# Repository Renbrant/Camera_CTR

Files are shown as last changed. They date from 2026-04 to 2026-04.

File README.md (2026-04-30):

# Camera CTR - High-Speed & Lightning Photography Trigger

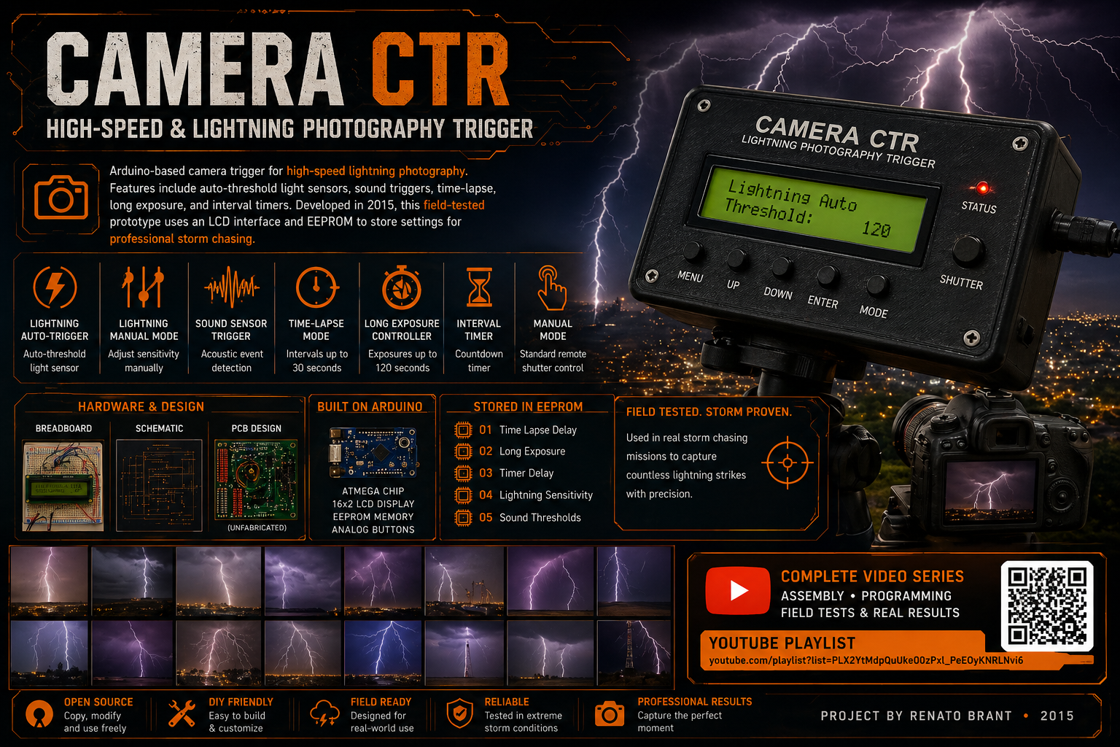
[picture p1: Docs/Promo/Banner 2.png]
Camera CTR Banner


### Description
**Arduino-based camera trigger for high-speed lightning photography. Features include auto-threshold light sensors, sound triggers, time-lapse, long exposure, and interval timers. Developed in 2015, this field-tested prototype uses an LCD interface and EEPROM to store settings for professional storm chasing.**

## Prototype & Hardware Design
The device evolved through several iterations, from early breadboard tests to a finalized prototype with a dedicated housing. 

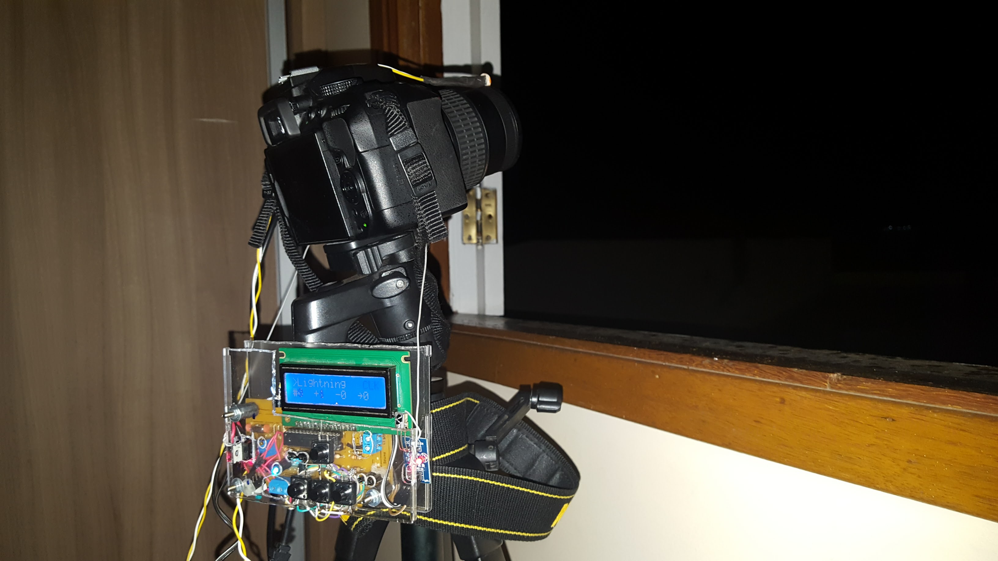
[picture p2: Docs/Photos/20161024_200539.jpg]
Camera CTR Prototype


### Hardware Schematics & PCB
Although the custom PCB was not manufactured at the time, the project includes complete design files for the circuit and board layout.

| Breadboard View | Schematic | PCB Design (Unfabricated) |
| :---: | :---: | :---: |
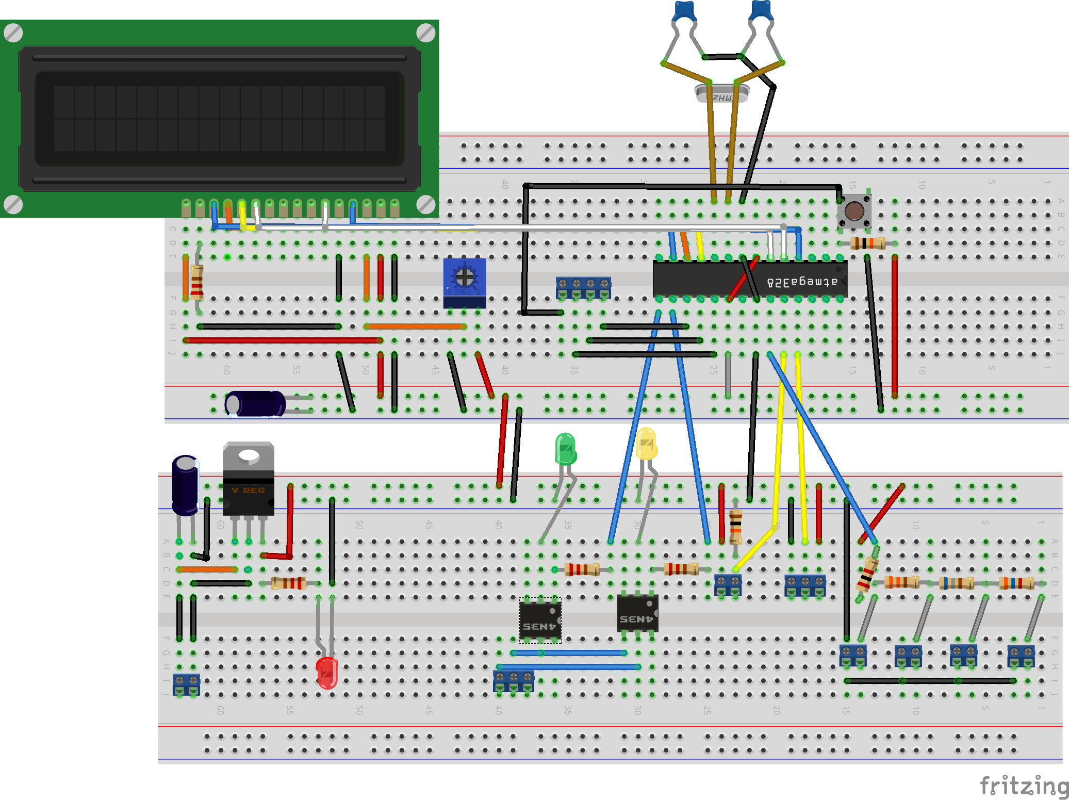
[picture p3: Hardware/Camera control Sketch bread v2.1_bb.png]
Breadboard
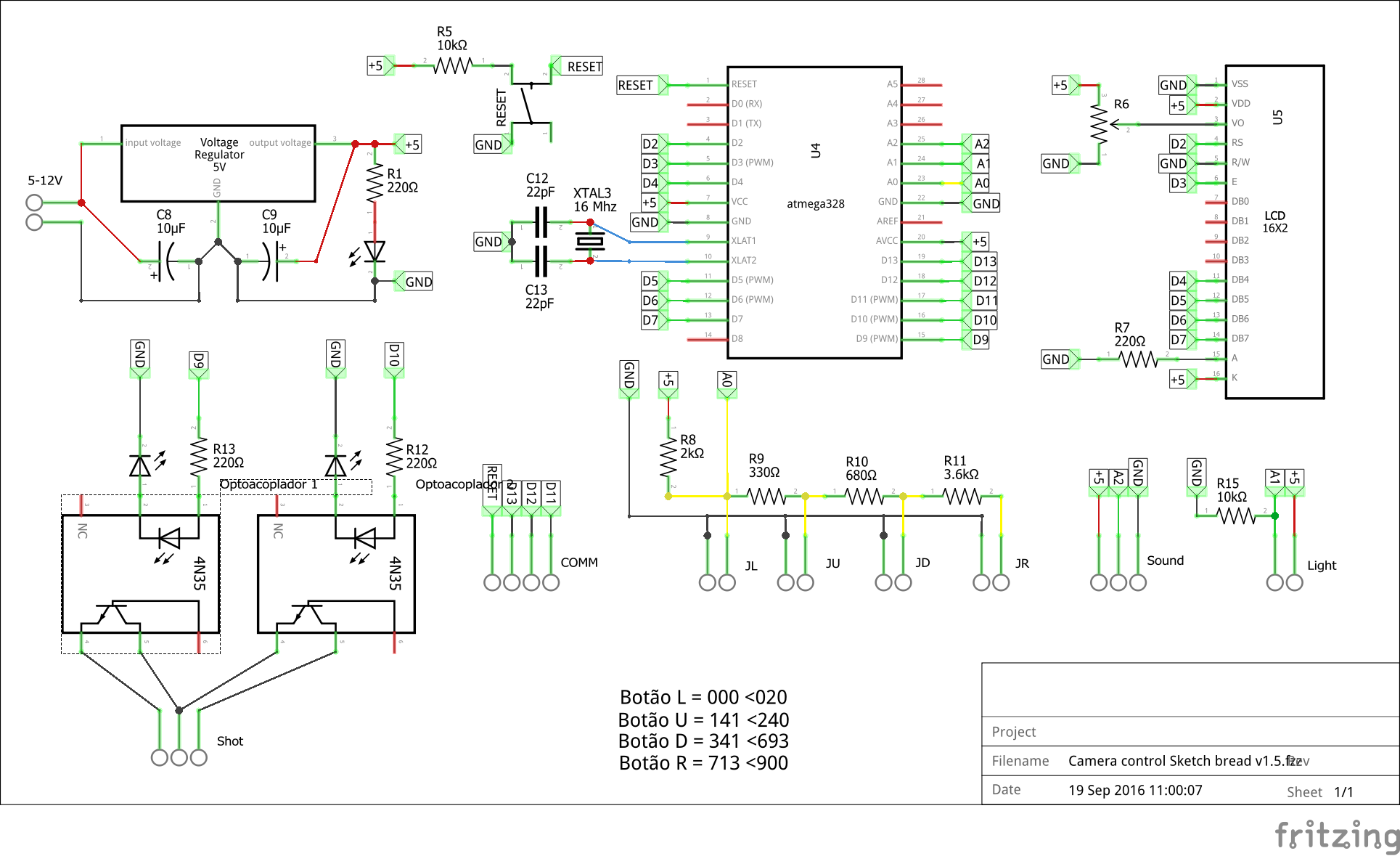
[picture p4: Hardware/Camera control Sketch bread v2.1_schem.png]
Schematic
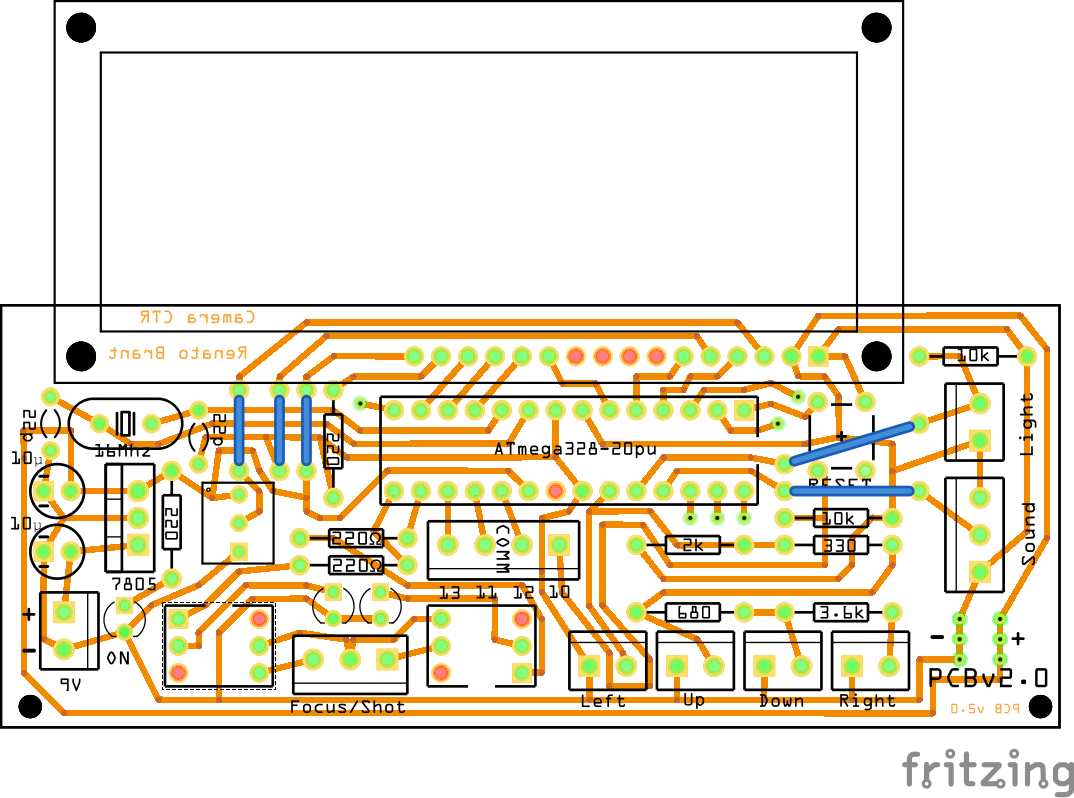
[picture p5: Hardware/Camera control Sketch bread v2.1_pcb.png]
PCB Layout
|  |  |  |

## Features
* **Lightning Auto-Trigger**: Automatically calculates sensitivity thresholds based on ambient light to capture strikes instantly.
* **Lightning Manual Mode**: Manual adjustment of light sensitivity for specific conditions.
* **Sound Sensor Trigger**: Fires the camera based on acoustic events with adjustable sensitivity.
* **Time-Lapse Mode**: Captures sequences with programmable intervals up to 30 seconds.
* **Long Exposure Controller**: Precision shutter control for exposures up to 120 seconds.
* **Interval Timer**: Countdown timer for delayed photography.
* **Manual Mode**: Standard digital remote shutter functionality.
* **Backlight Management**: Dedicated control to toggle LCD light during night shoots.

## Hardware Configuration
The project is built on the Arduino platform using an ATmega chip and a 16x2 LCD. 
The pin mapping as defined in the source code is:

| Component | Pin |
| :--- | :--- |
| **Camera Shutter (Trigger)** | 10 |
| **Ready/Status LED** | 9 |
| **Photometer (Light Sensor)** | A1 |
| **Sound Sensor** | A2 |
| **LCD Backlight Control** | A5 |
| **Keypad (Analog Buttons)** | A0 |

### LCD Pinout (LiquidCrystal)
* **RS**: 2, **Enable**: 3, **D4-D7**: 4, 5, 6, 7.

## Software Logic & Memory
The system utilizes the internal EEPROM to persist user settings across power cycles:
* **EEPROM 01**: Time Lapse Delay settings.
* **EEPROM 02**: Long Exposure parameters.
* **EEPROM 03**: Timer Delay.
* **EEPROM 04**: Lightning Manual Sensitivity.
* **EEPROM 05**: Sound Sensor Thresholds.

## Photo Gallery (Captured with Camera CTR)
Below are photos captured during storms, demonstrating the precision of the synchronized trigger with lightning discharges.

| | | |
|:---:|:---:|:---:|
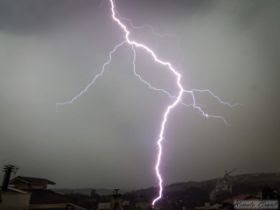
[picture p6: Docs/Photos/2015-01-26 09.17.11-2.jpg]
Lightning 1
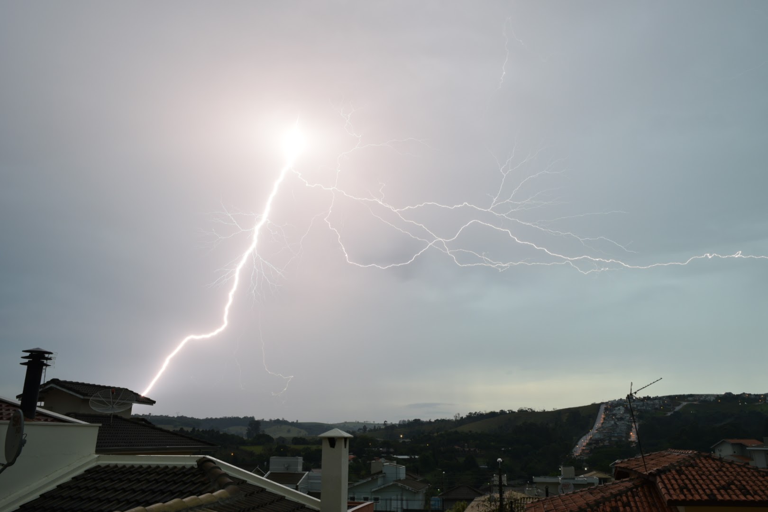
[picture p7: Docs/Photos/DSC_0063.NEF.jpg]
Lightning 2
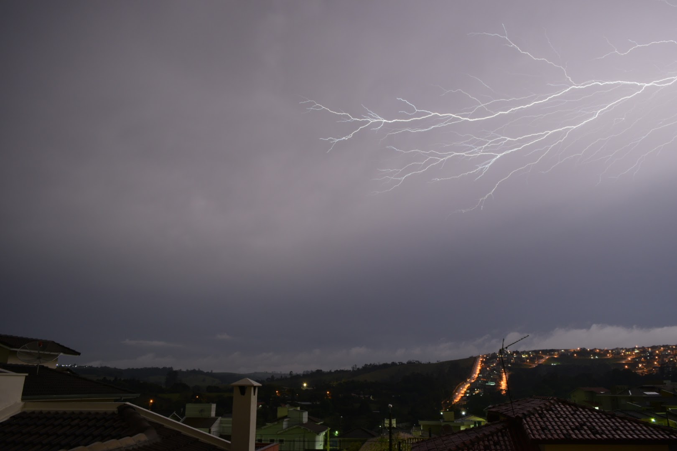
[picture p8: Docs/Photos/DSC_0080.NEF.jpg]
Lightning 3
|  |  |  |
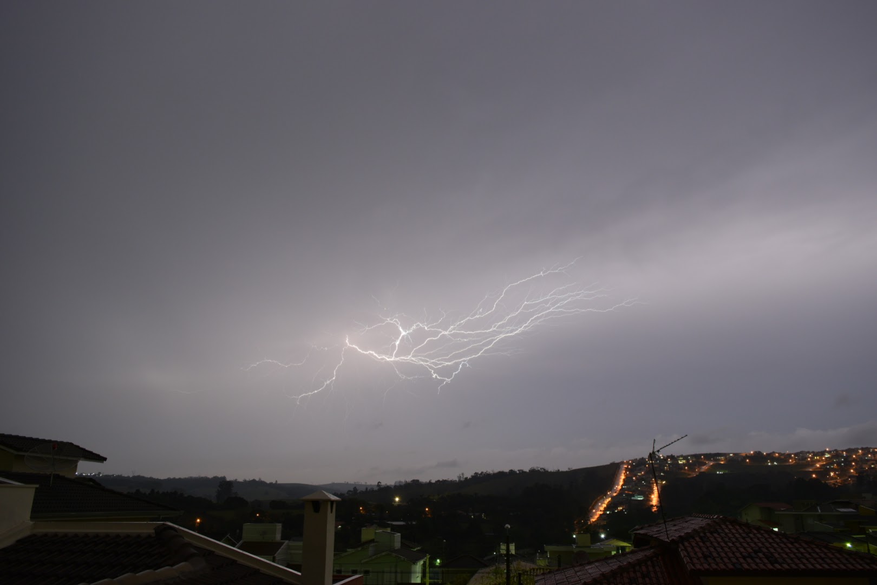
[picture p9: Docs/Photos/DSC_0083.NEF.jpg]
Lightning 4
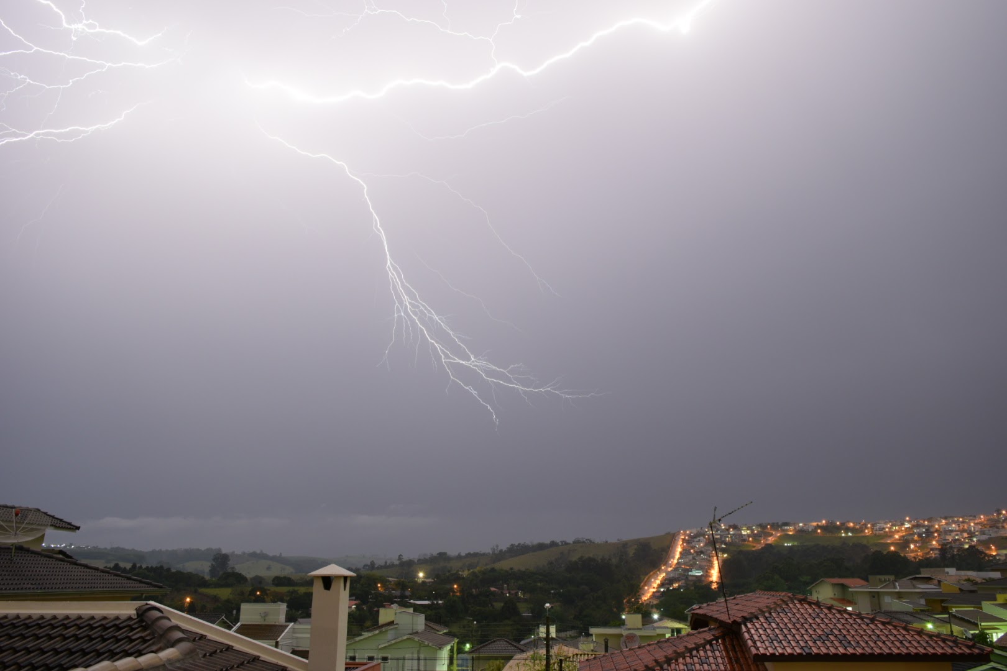
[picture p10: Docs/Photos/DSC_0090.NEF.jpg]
Lightning 5
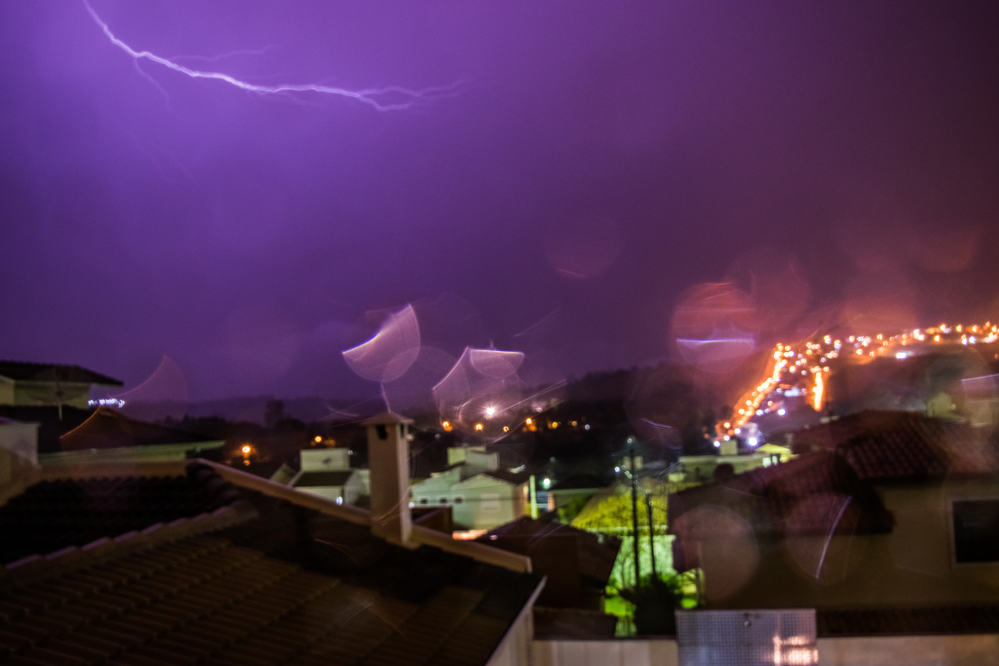
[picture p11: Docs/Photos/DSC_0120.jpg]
Lightning 6
|  |  |  |
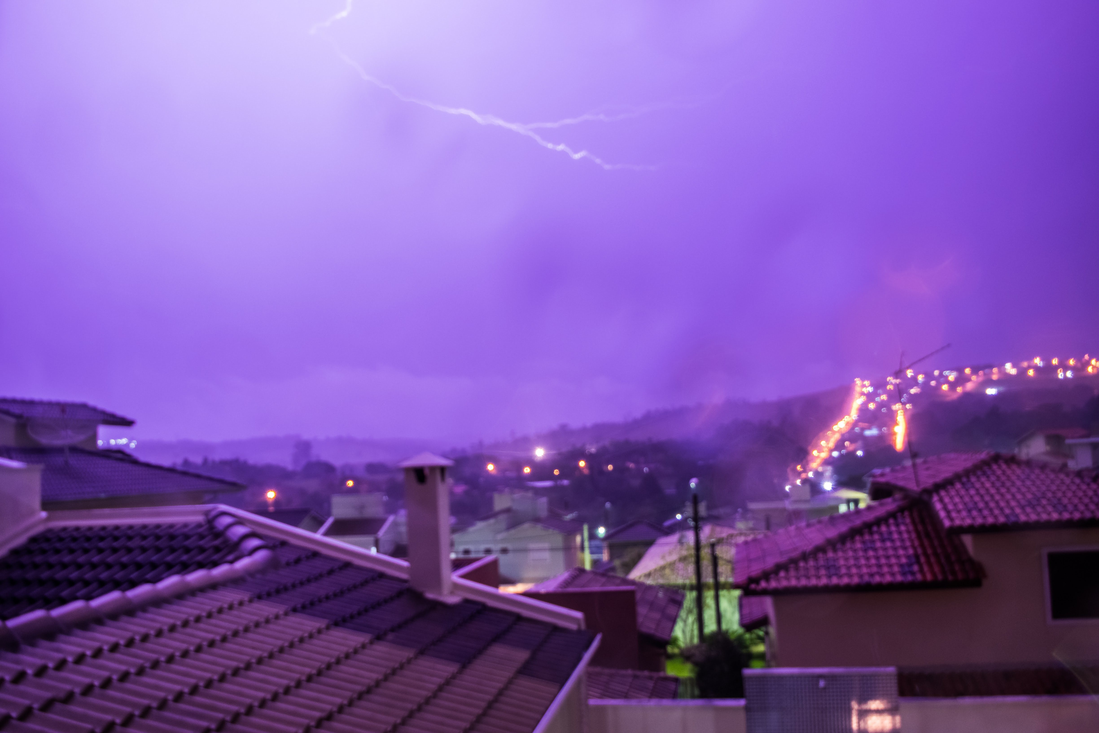
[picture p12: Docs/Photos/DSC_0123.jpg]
Lightning 7
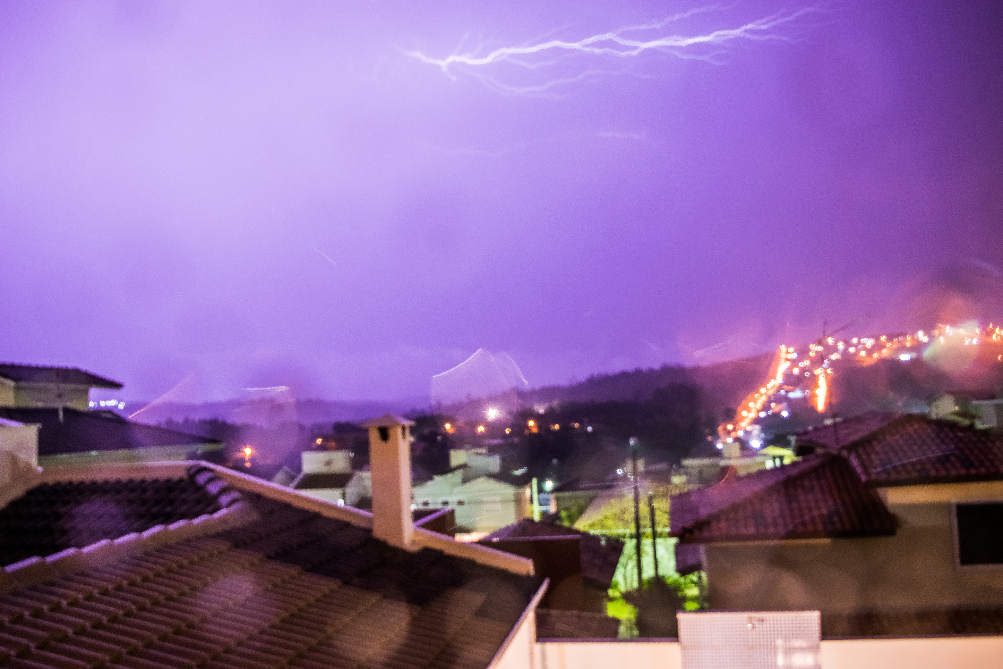
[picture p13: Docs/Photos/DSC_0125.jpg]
Lightning 8
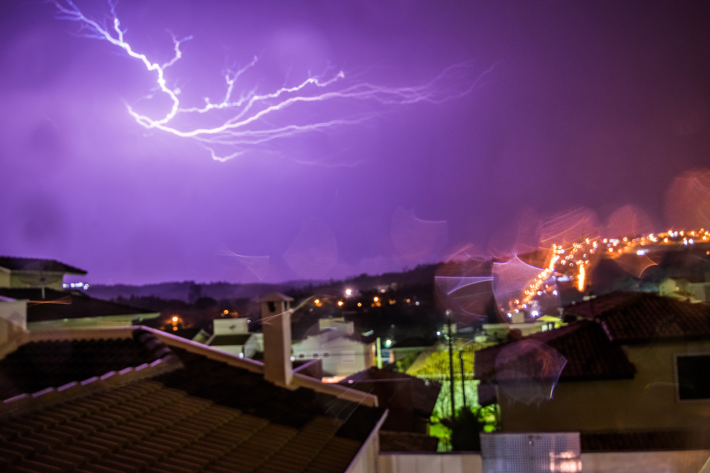
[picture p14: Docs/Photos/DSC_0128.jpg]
Lightning 9
|  |  |  |
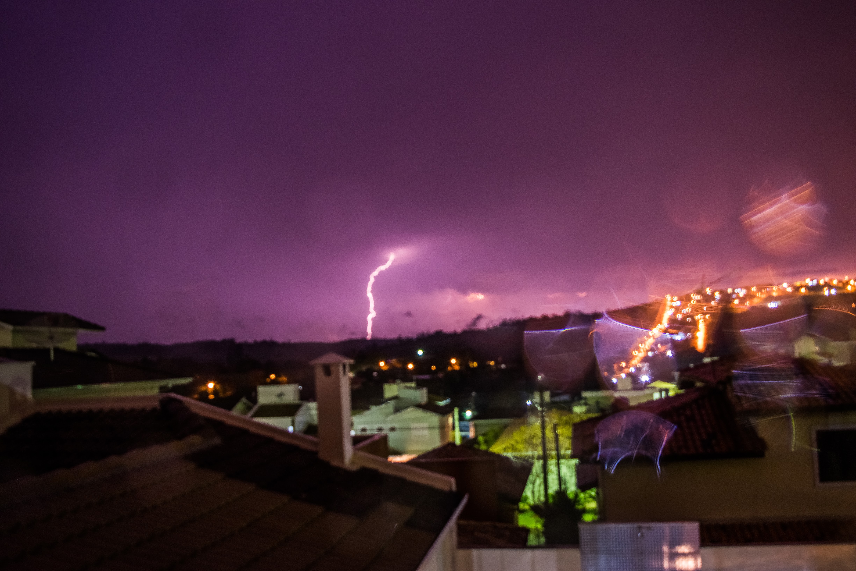
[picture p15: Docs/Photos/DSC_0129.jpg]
Lightning 10
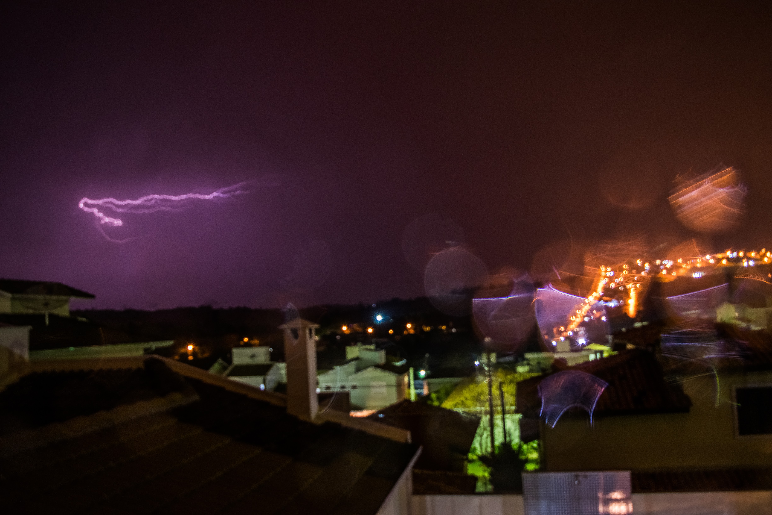
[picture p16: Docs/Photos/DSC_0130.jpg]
Lightning 11
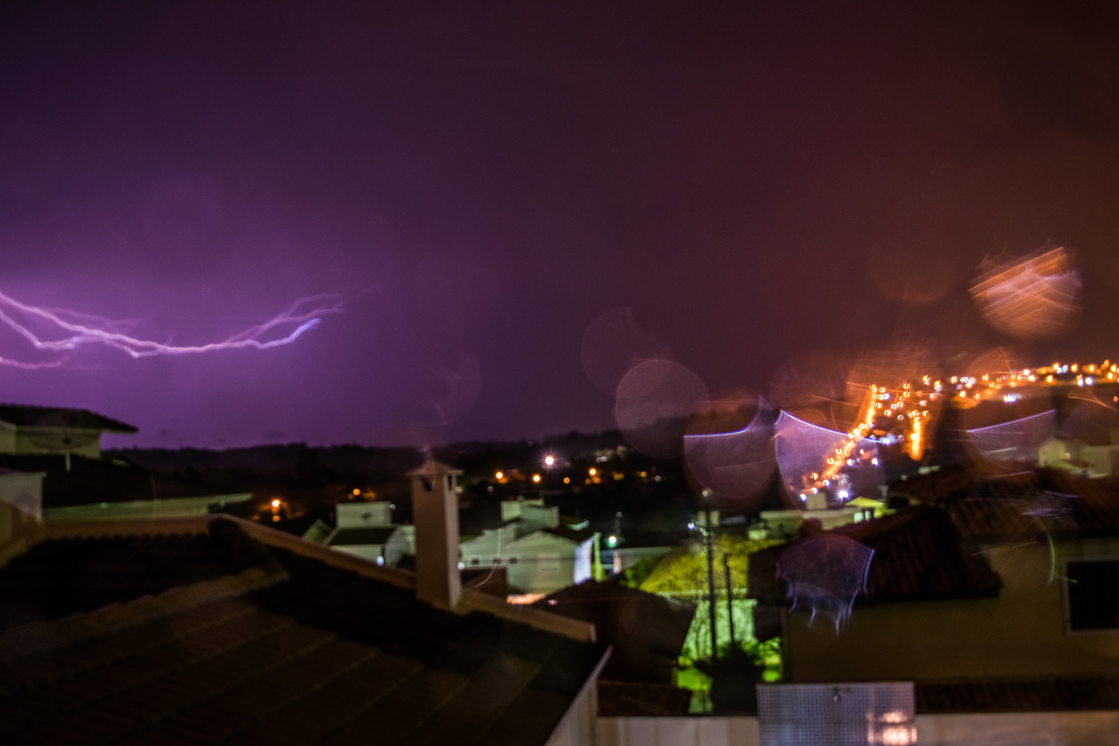
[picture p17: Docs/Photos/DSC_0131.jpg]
Lightning 12
|  |  |  |
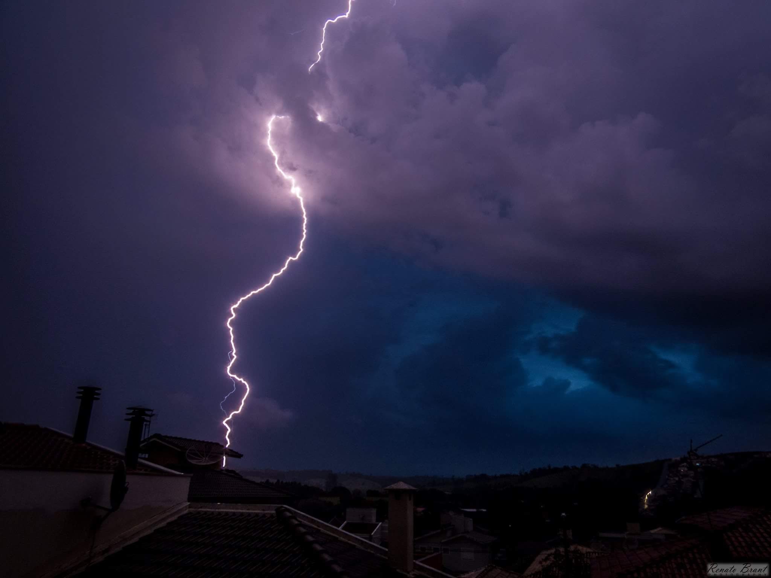
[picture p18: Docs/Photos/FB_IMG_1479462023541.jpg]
Lightning 13
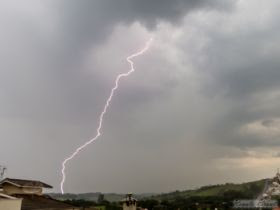
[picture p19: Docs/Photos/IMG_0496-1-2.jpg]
Lightning 14
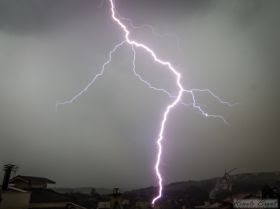
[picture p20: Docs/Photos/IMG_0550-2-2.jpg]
Lightning 15
|  |  |  |

## Open Source & Contributions
This is an **open project**. You are free to copy, modify, and use it for your own photography projects. If you find this helpful or use it in your work, a citation or credit is greatly appreciated!

## Video Documentation
A comprehensive video series covers the hardware assembly, programming logic, and real-world field tests:

**[📺 Camera CTR Project - YouTube Playlist](https://www.youtube.com/playlist?list=PLX2YtMdpQuUke00zPxl_PeEOyKNRLNvi6)**

### Technical Highlights
* **Programming Logic**: Detailed breakdown of the Arduino code structure and menu navigation.
* **Field Testing**: Real footage of the sensor triggering the camera during lightning storms.

## Version History (2015-2016)
* **v0.1 - v0.3**: Initial counters for Time Lapse, Long Exposure, and Timer.
* **v0.5 - v0.7**: Implementation of Lightning Photo, threshold logic, and two-color LED.
* **v0.8 - v0.10**: Integration of Sound Sensor and timing corrections.
* **v0.12 - v0.16**: Final UI refinements, Manual Mode, and Backlight management.

---
*Project by Renato Brant.*

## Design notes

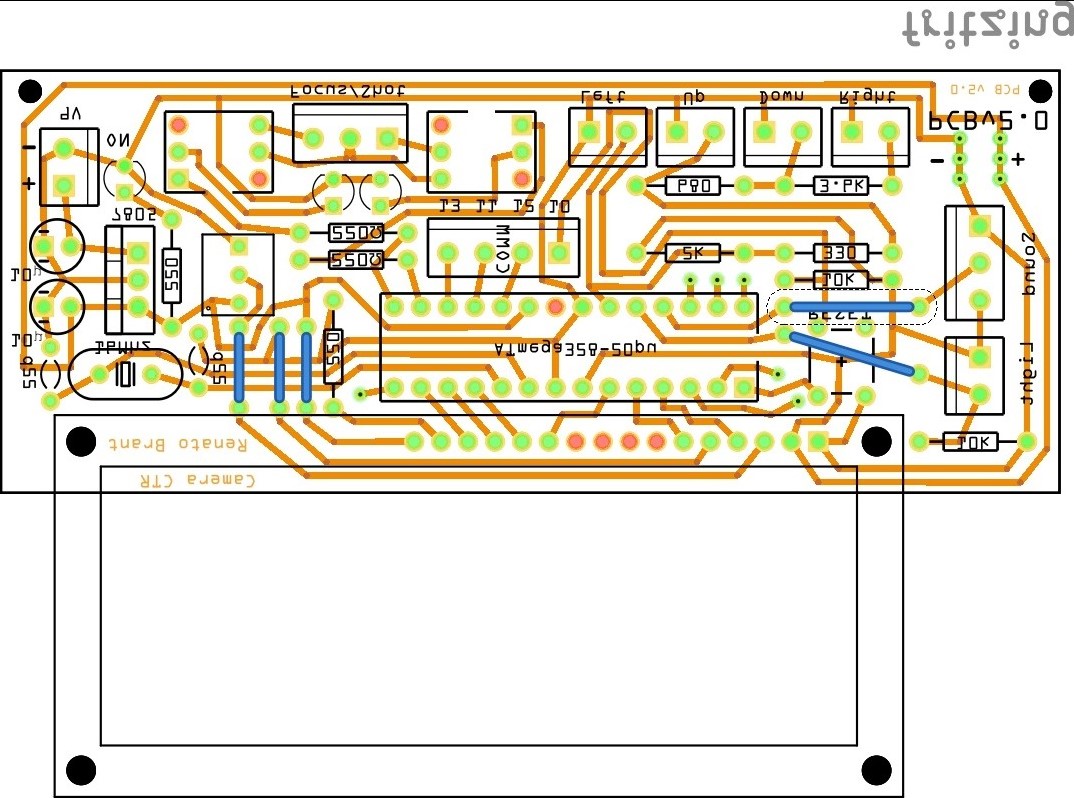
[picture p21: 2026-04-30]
Hardware/Camera control Sketch bread v2.0_pcb 2.jpg

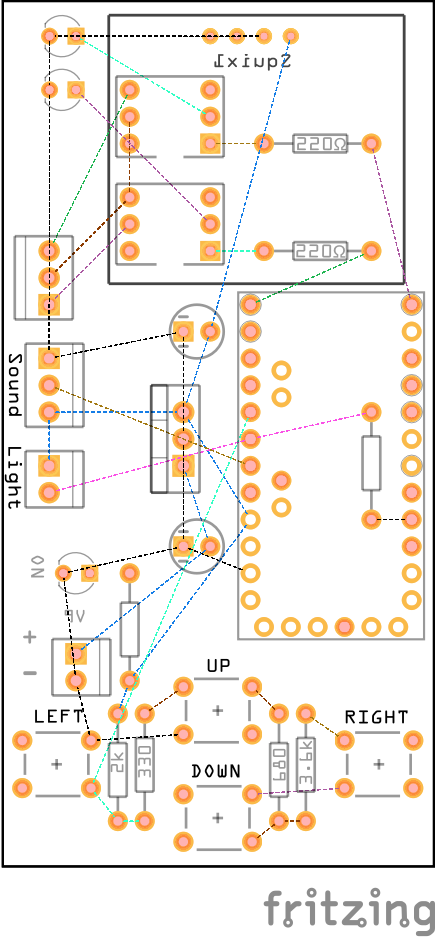
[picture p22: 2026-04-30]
Hardware/Camera control Sketch bread v3_pcb.png

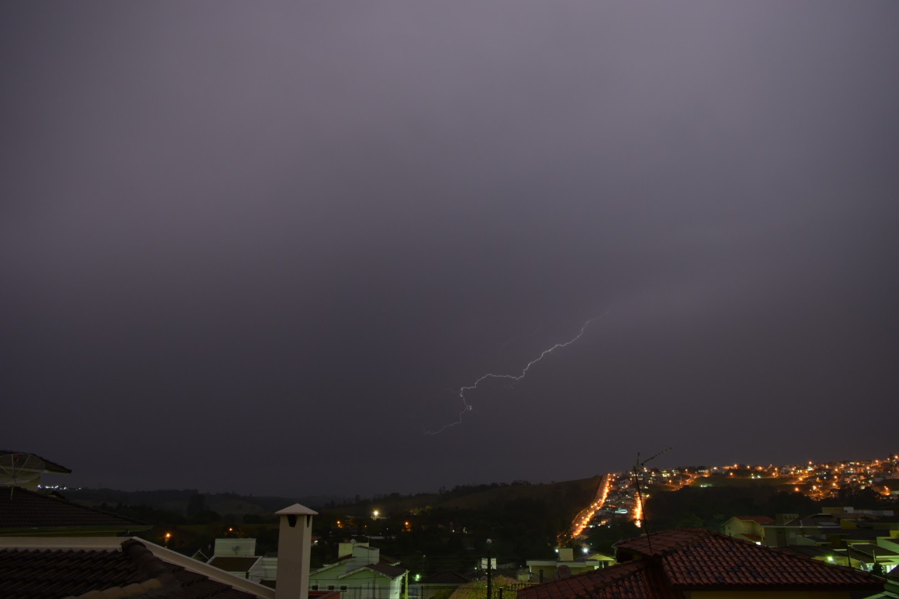
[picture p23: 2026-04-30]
Docs/Photos/DSC_0091.NEF.jpg

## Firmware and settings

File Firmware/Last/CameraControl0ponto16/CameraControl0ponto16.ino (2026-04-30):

/*+++++++++++++++++++++++++++++++++++++++++++++++++++
  Author      : Renato Brant
  Date        : 14 May 2016
  Project     : Camera CTR
  Version     : 0.15
  Description : 0.1 Ccontador do Time Lapse funcionando
                0.2 Contador do Long Exposure funcionando
                0.3 Contador Timer funcionando
                    Melhorias no contador do Time Lapse
                    Melhorias no MainMenuDisplay
                0.4 Habilitaçao do Pin1 como camera
                0.5 lightining photo funcionando
                    Não é mais possivel seleceionar valores negativos
                    Acrescentada opção de saida do LE
                0.6 Led de duas cores
                0.7 Luz min e max
                0.8 Inculindo Sound Sensor
                0.8b voltando a mexer depois de um tempo
                0.9 Alterado os valores do keypad
                0.10 Colocado limite dos delays
                     Alterando a logica focus+shot
                     Corrigido problema dos tempos (long)
                0.11 alteração das portas do ATmega para facilitar trilhas da placa
                0.12  correcao dos textos
                      correcao do LED durante lightning/Time Lapse/Timer
                      Acrescentado modo Manual
                0.13 Controle de backlight no A5
                0.14 Abertura durante o Lightning
                0.15 Acresentando Lightning auto
                     Inverte o estado do backlight nos Lightning



  +++++++++++++++++++++++++++++++++++++++++++++++++++*/

#include <EEPROM.h>
#include <LiquidCrystal.h>

//LiquidCrystal lcd (<pino RS>, <pino enable>, <pino D4>, <pino D5>, <pino D6>, <pino D7>)
//    RS=D2    Vss=GND
//    E =D3    Vdd=5v
//    D4=D4    Vo =potenciometro
//    D5=D5    R/W=GND
//    D6=D6    A  =GND c/ 220ohm
//    D7=D7    K  =5v

LiquidCrystal lcd(2, 3, 4, 5, 6, 7);

//caracteres da maquina fotografica
byte CAM1[8] = {0b00000, 0b00000, 0b00000, 0b01111, 0b11111, 0b11111, 0b11111, 0b11111};
byte CAM2[8] = {0b00111, 0b01111, 0b11111, 0b11111, 0b11110, 0b11000, 0b10001, 0b10000};
byte CAM3[8] = {0b11100, 0b11110, 0b11111, 0b11111, 0b01111, 0b00011, 0b11001, 0b01101};
byte CAM4[8] = {0b00000, 0b00000, 0b00000, 0b11110, 0b11111, 0b10011, 0b10011, 0b11111};
byte CAM5[8] = {0b11111, 0b11111, 0b11111, 0b11111, 0b11111, 0b11111, 0b11111, 0b01111};
byte CAM6[8] = {0b00000, 0b00000, 0b10000, 0b10000, 0b11000, 0b11110, 0b11111, 0b11111};
byte CAM7[8] = {0b00100, 0b00100, 0b00001, 0b00001, 0b00011, 0b01111, 0b11111, 0b11111};
byte CAM8[8] = {0b11111, 0b11111, 0b11111, 0b11111, 0b11111, 0b11111, 0b11111, 0b11110};

//pins
int keypad_pin = A0;
int cameraPin = 10;
int readyPin = 9;
int photometroPin = A1;
int somPin = A2;
int BacklightPin = A5;

//Valores do keypad
int keypad_value = 0;
int keypad_value_old = 0;

// Valores do Keypad
//Botao 1 = 0
//Botao 2 = 141
//Botao 3 = 341
//Botao 4 = 713
// Resistencias: 2k, 330, 690, 3.6k

//Valores da luz
int luzAtual1023 = 0;
int luzAtual100 = 0;
int luzPhoto = 0;
int luzMin = 100;
int luzMax = 0;

//Valores do som
int somAtual1023 = 0;
int somAtual100 = 0;
int somPhoto = 0;
int somMin = 100;
int somMax = 0;

//Variaveis de tempo
long TLdelay = 0;
long LEdelay = 5;
long TIdelay = 5;
long TotalTime = 0;
long lastDebounceTime = 0;

char btn_push;

byte mainMenuPage = 1;
byte mainMenuPageOld = 1;
byte mainMenuTotal = 7;

//#####################################################################################################################
void setup()
{
  lcd.begin(16, 2); //Initialize a 2x16 type LCD
  pinMode(cameraPin, OUTPUT);
  pinMode(readyPin, OUTPUT);
  pinMode(BacklightPin, OUTPUT);
  pinMode(photometroPin, INPUT);
  Abertura();
  MainMenuDisplay();
  delay(1000);

  TLdelay = EEPROM.read(01);
  LEdelay = EEPROM.read(02);
  TIdelay = EEPROM.read(03);
  luzPhoto = EEPROM.read(04);
  somPhoto = EEPROM.read(05);

}


//#####################################################################################################################
void loop()
{
  btn_push = ReadKeypad();

  MainMenuBtn();

  if (btn_push == 'R') //enter selected menu
  {
    WaitBtnRelease();
    switch (mainMenuPage)
    {
      case 1:
        TimeLapse();
        break;
      case 2:
        Timer();
        break;
      case 3:
        Lightning();
        break;
      case 4:
        Lightning_auto();
        break;
      case 5:
        LongExposure();
        break;
      case 6:
        Sound();
        break;
      case 7:
        Manual();
        break;
    }

    MainMenuDisplay();
    WaitBtnRelease();
  }

  delay(10);
}

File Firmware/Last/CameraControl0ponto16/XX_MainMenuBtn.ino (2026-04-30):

void MainMenuBtn()
{
    WaitBtnRelease();
    if(btn_push == 'D')
    {
        mainMenuPage++;
        if(mainMenuPage > mainMenuTotal)
          mainMenuPage = 1;
    }
    else if(btn_push == 'U')
    {
        mainMenuPage--;
        if(mainMenuPage == 0)
          mainMenuPage = mainMenuTotal;    
    }
   
    if(mainMenuPage != mainMenuPageOld) //only update display when page change
    {
        MainMenuDisplay();
        mainMenuPageOld = mainMenuPage;
    }
}
